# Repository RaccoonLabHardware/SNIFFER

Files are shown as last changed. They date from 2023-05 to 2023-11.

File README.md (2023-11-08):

# SNIFFER v1.4.0 hardware 

| View | Top | Bottom |
| ---- | --- | --- |
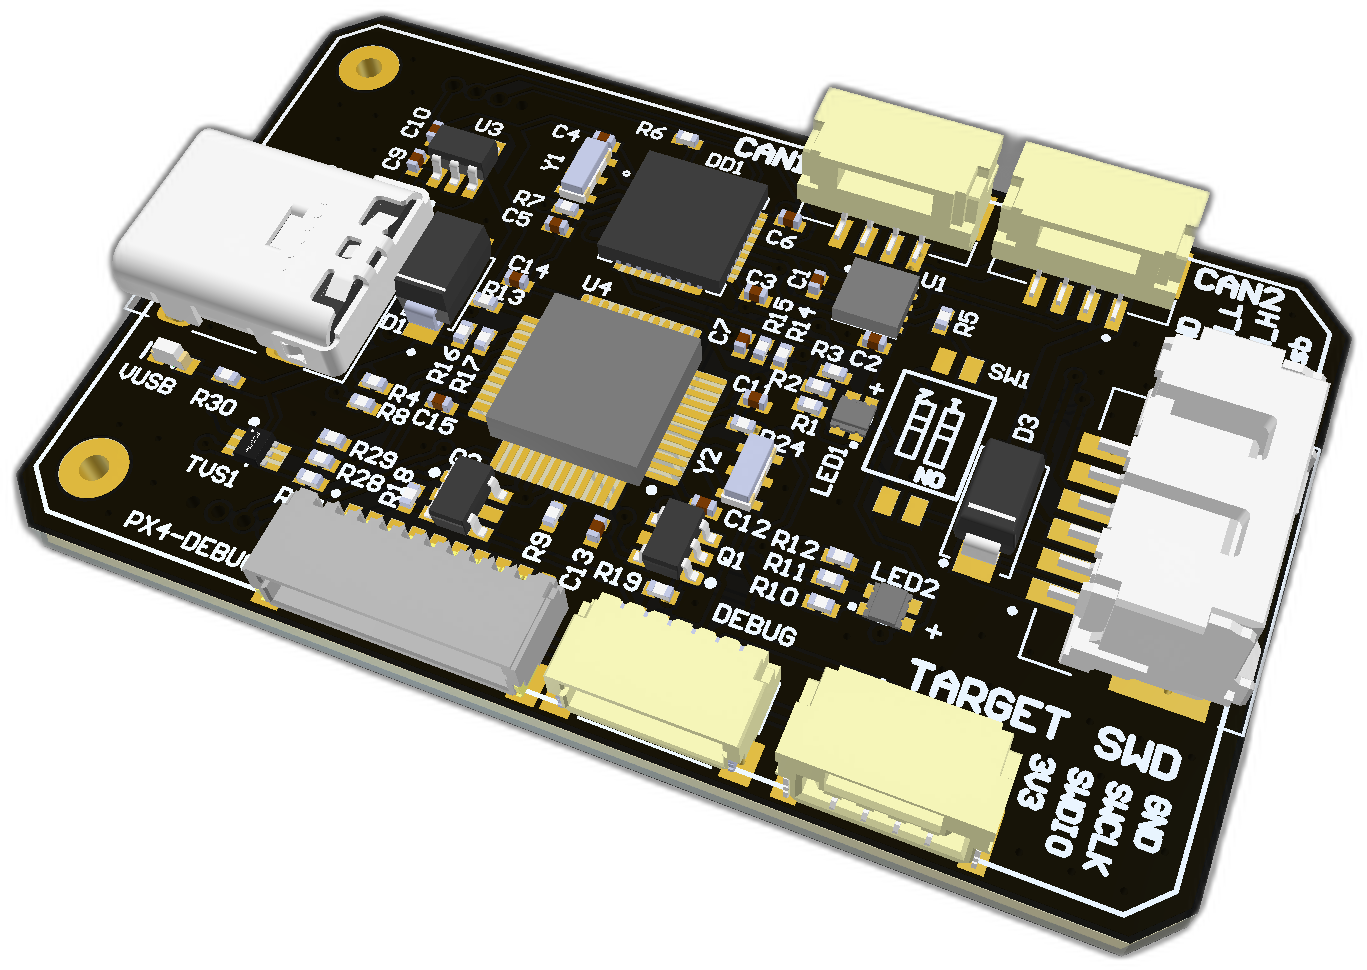
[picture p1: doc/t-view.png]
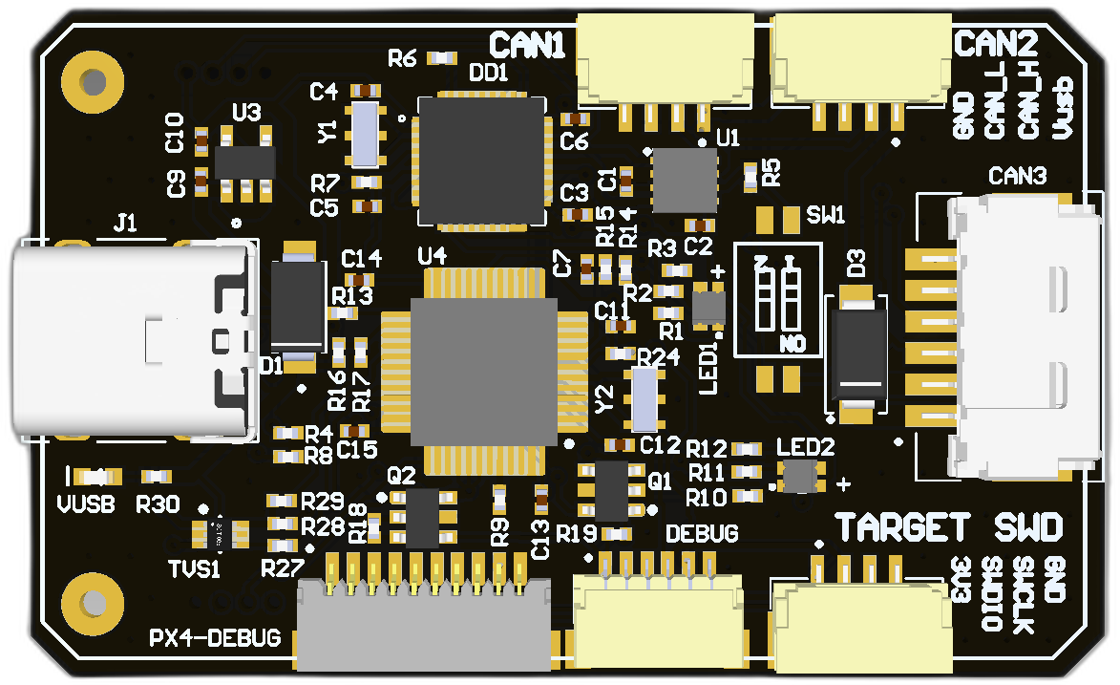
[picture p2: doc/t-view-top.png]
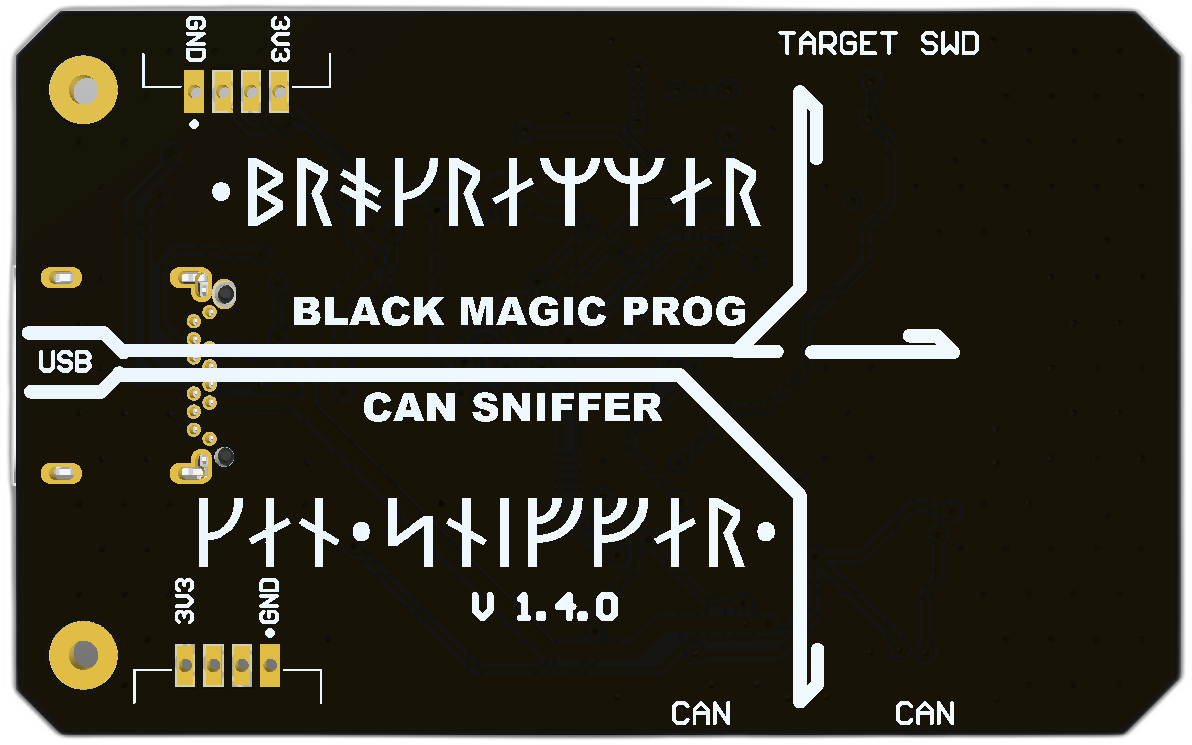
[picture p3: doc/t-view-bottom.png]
|  |  |  |
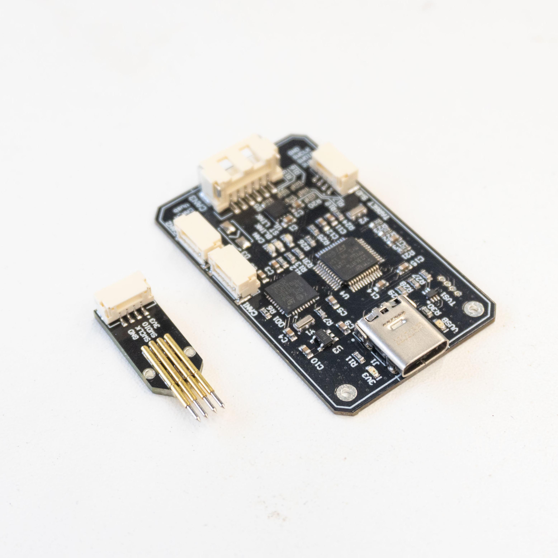
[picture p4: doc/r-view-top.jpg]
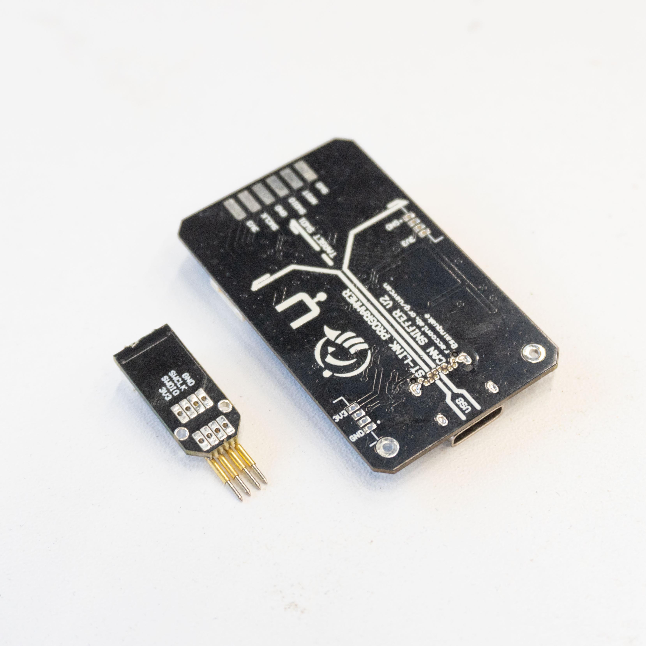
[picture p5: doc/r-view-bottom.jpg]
|  |  |  |

## Features

## Wiring

Schematic features. Schematic can be provided via issue.

**Connectors**

The node has connectors which are described in the table below.

| N | Connector | Description |
| - | - | - |
| 1 | CAN1, CAN2, TARGET SWD |  |
| 2 | CAN3 |  |
| 3 | J1 |  |
| 4 | SWD1, SWD2 |  |

[Here](https://docs.raccoonlab.co/guide/wires/) you can find manufacturer part number of connectors it self and its mates.

## Pin configuration and functions

| Pin N | CAN1 | Pin N | CAN2 | Pin N | TARGETSWD | Pin N | CAN3 | Pin N | J1 | Pin N | SWD1 | Pin N | SWD2 |
| ----- | --- | ----- | --- | ----- | --- | ----- | --- | ----- | --- | ----- | --- | ----- | --- |
| 1 | VBUS | 1 | VBUS | | | 1 | Vin | A1 | GND | 1 | GND | 1 | GND |
| 2 | CAN_H | 2 | CAN_H | | | 2 | Vin | A12 | GND | 2 | SWLK | 2 | SWLK_p |
| 3 | CAN_L | 3 | CAN_L | | | 3 | CAN_H | A4 | VBUS | 3 | SWDIO | 3 | SWDIO_p |
| 4 | GND | 4 | GND | | | 4 | CAN_L | A5 | IP0 | 4 | 3.3 | 4 | 3.3 |
| SH1 | GND | SH1 | GND | | | 5 | GND | A6 | D+ | | | | |
| SH2 | GND | SH2 | GND | 6 | GND | A7 | D- | | | | |
| P1 | GND | A9 | VBUS | | | | |
| P2 | GND | B1 | GND | | | | |
| B12 | GND | | | | |
| B4 | VBUS | | | | |
| B5 | IP1 | | | | |
| B6 | D+ | | | | |
| B7 | D- | | | | |
| B9 | VBUS | | | | |
| SH1 | GND | | | | |
| SH2 | GND | | | | |
| SH3 | GND | | | | |
| SH4 | GND | | | | |
| SH5 | GND | | | | |
| SH6 | GND |

Here you can see all connections of MCU.

| MCU PIN | PIN Numer | NET Name | Description |
| --- |  -- | ---  | - |
| PB13 |  26 | VBUS_SENSE  |  |
| PA8 |  29 | USB_DP_PULLUP  |  |
| PA12 |  33 | USB_DP |  |
| PA11 |  32 | USB_DM |  |
| PA0-WKUP |  7  | TX2/B2 |  |
| PA2 |  9  | TX2/B2 |  |
| PB7 |  43 | TRSWO |  |
| PB3 |  39 | TRACESWO |  |
| PB1 |  16 | T3CH4/ADC9  |  |
| PB0 |  15 | T3CH3/ADC8  |  |
| PA7 |  14 | T3CH2/ADC7  |  |
| PA6 |  13 | T3CH1/ADC6  |  |
| PA14 |  37 | SWLK_p |  |
| PA14/JTCK/SWCLKI/O |  28 | SWLK |  |
| PA13 |  34 | SWDIO_p |  |
| PA13/JTMS/SWDIOI/O |  25 | SWDIO |  |
| NRST |  7  | STM_RST |  |
| PA15/JTDI |  29 | SPI1_SS |  |
| PB3/JTDO |  30 | SPI1_SCK |  |
| PB5 |  32 | SPI1_MOSI |  |
| PB4/JNTRST |  31 | SPI1_MISO |  |
| PB7 |  34 | SDA/A1 |  |
| PB6 |  33 | SCL/A2 |  |
| PA8 |  20 | RXI |  |
| PA9 |  21 | RXI |  |
| PA10 |  31 | RXI |  |
| PA3 |  10 | RX2/B1 |  |
| PA10 |  22 | RX1/C1 |  |
| PA9 |  30 | RX1/C1 |  |
| PB1 |  19 | PWR_BR |  |
| NRST |  4  | NRST |  |
| PD1-OSC_OUT |  6  | NetU4_6 |  |
| PD0-OSC_IN |  5  | NetU4_5 |  |
| PB12 |  25 | NetR13_2 |  |
| BOOT0 |  44 | NetR9_1 |  |
| OSC_OUT/PD1 |  3  | NetDD1_3 |  |
| OSC_IN/PD0 |  2  | NetDD1_2 |  |
| PB0 |  18 | NetC7_2 |  |
| PA5 |  12 | LED_BLUE |  |
| PB11 |  22 | LED2 |  |
| PB10 |  21 | LED1 |  |
| PB2 |  20 | LED0 |  |
| PA4 |  11 | LED |  |
| PA4 |  14 | iTMS_SWDIO  |  |
| PA1 |  11 | iTMS_DIR |  |
| PA6 |  16 | iTDO |  |
| PA3 |  13 | iTDI |  |
| PA5 |  15 | iTCK_SWCLK  |  |
| PA7 |  17 | iRST_SENSE  |  |
| PA2 |  12 | iRST |  |
| VSSA |  5  | GND |  |
| PB2/BOOT1 |  17 | GND |  |
| VSS_2 |  18 | GND |  |
| VSS_3 |  26 | GND |  |
| VSS_1 |  36 | GND |  |
| VSSA |  8  | GND |  |
| VSS_1 |  23 | GND |  |
| VSS_2 |  35 | GND |  |
| VSS_3 |  47 | GND |  |
| PA12 |  24 | CAN_TXD |  |
| PA11 |  23 | CAN_RXD |  |
| BOOT0 |  35 | BOOT0 |  |
| PA1 |  8  | ADC_5V |  |
| VDD_1 |  1  | 3.3 |  |
| VDDA |  6  | 3.3 |  |
| VDD_2 |  19 | 3.3 |  |
| VDD_3 |  27 | 3.3 |  |
| VBAT |  1  | 3.3 |  |
| VDDA |  9  | 3.3 |  |
| VDD_1 |  24 | 3.3 |  |
| VDD_2 |  36 | 3.3 |  |
| PB4 |  40 | 3.3 |  |
| PB5 |  41 | 3.3 |  |
| PB6 |  42 | 3.3 |  |
| VDD_3 |  48 | 3.3 |  |

## Specifications

**Mechanical**

Scheme is shown on the picture below. CAN model can be provided via email request or issue on github or downloaded on GrabCAD (opens new window).

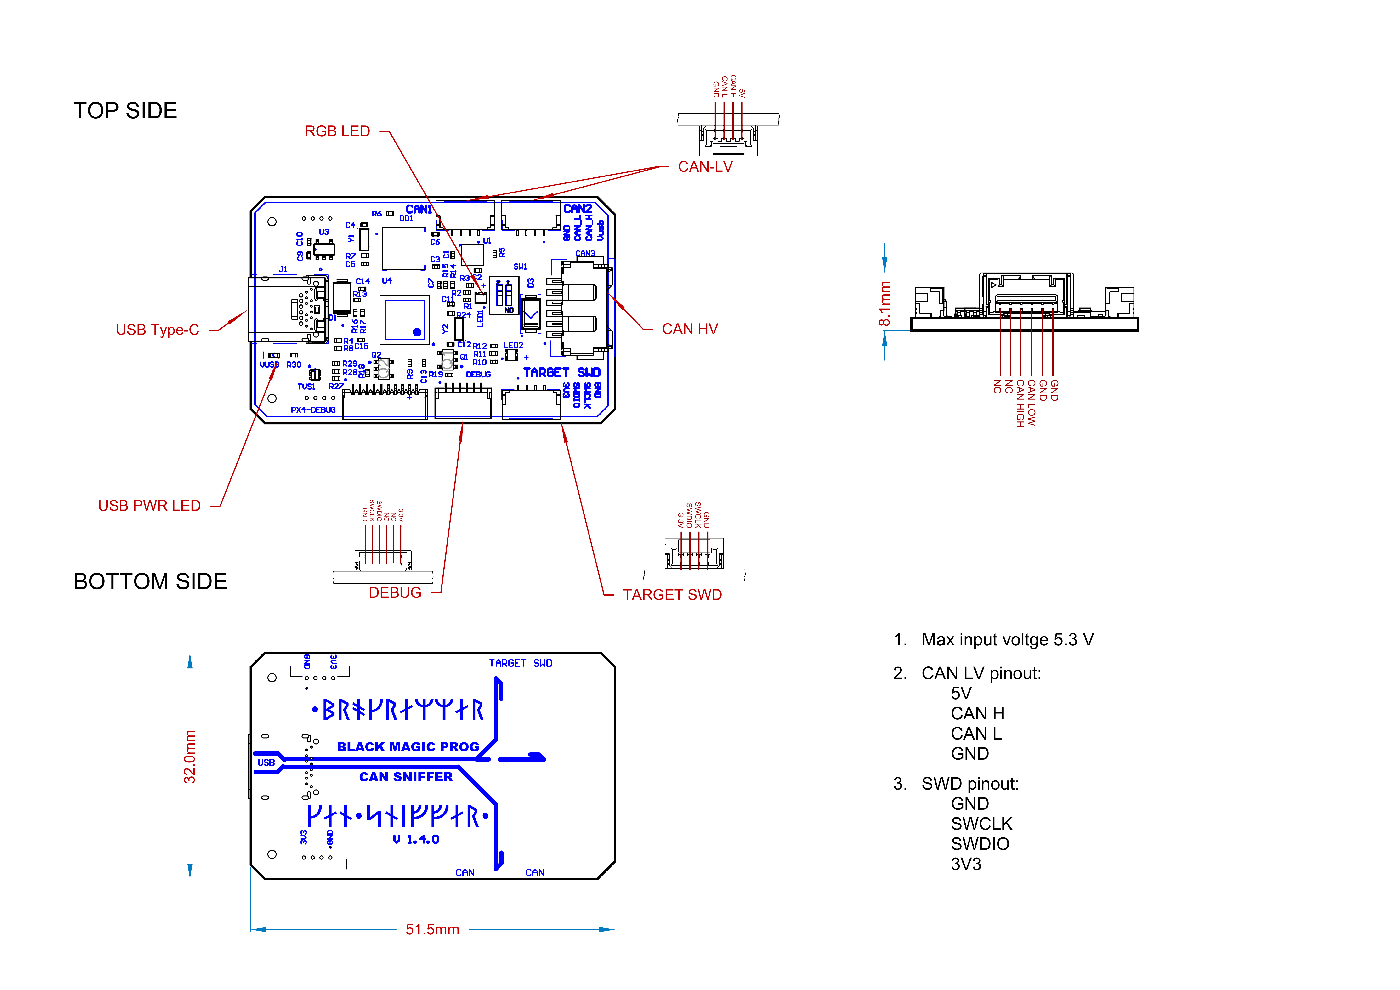
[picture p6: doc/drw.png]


| | Width, mm | Length, mm | Height, mm |
| ----- | --- | --- | --- |
|Outline| 51.9 | 32.0 | 8.1 |
|PCB | 51.5 | 32.0 | 1.6 |

Total weight of device less than 50 g.

### Housing

Information about case presented here.

### Absolute Maximum Ratings

### Recommended operating conditions

### ESD ratings

### MTFF

## Integration

**Recommended mechanical mounting**

**Connection example diagram**

### Power Supply Recommendations

Device is designed to operate from an input voltage supply range between 4.5 V and 5.5 V over CAN2 or CAN3 connector, or 5.5 - 30 V from CAN1. This input supply must be able to withstand the maximum input current and maintain a stable voltage. The resistance of the input supply rail should be low enough that an input current transient does not cause a high enough drop that can cause a false UVLO fault triggering and system reset. The amount of bulk capacitance is not critical, but a 47-uF or 100-uF electrolytic capacitor is a typical choice.

## Revision history

|View |Version| Date| Description|
|- |- |- |- |

## Order details

### PCB Specification Selection

- Board type : Panel by PCBWay
- Break-away rail: Yes
- Instructions:
~~~
Final size is larger ( 51.9 x 32.0 mm ) than board it self ( 51.5 x 32.0 mm), 
take a look at the picure in attachements. 
Panel should be designed to be able to install PWM1, PWM2 while assembly.
~~~
- Route Process: Panel as PCBWay prefer
- X-out Allowance in Panel:  Accept

- Size (single): 51.5 x 32.0 mm
- Quantity (single): 200
- Layers: 2 -   ['Top Layer', 'Bottom Layer'] check [PCBway layer stack](https://www.pcbway.com/multi-layer-laminated-structure.html)

- Material: FR-4
- FR4-TG: TG 150-160
- Thickness: 1.6
- Min Track/Spacing: 7/7mil (0.17 mm)
- Min Hole Size: 0.3 mm
- Solder Mask: Black
- Silkscreen: White
- Edge connector: No
- Surface Finish: HASL with lead
- Yes - Tick means you accept we might change "HASL" to "ENIG" at our discretion without extra charge.
- Via Process: Tenting vias
- Finished Copper: 1 oz Cu
- Other Special request:
~~~
Final size is larger ( 51.9 x 32.0 mm ) than board it self ( 51.5 x 32.0 mm )
~~~

### Assembly Service

- Turnkey
- Board type : Panelized PCBs
-  Assembly Side(s): Both sides
- Quantity: 200
- Contains Sensitive components/parts - No; 
- Do you accept alternatives/substitutes made in China? - Yes

- Number of Unique Parts: 0
- Number of SMD Parts: 0
- Number of BGA/QFP Parts: 0
- Number of Through-Hole Parts: 0

### Additional Options

- Firmware loading: Yes
- Detailed information of assembly:
~~~
Firmware is in attachements.
Take a look at the picure in attachements should be installed from the side.
~~~

## Device and Documentation Support

- [User manual]()
- [Hardware docs](doc/doc.pdf)

## Device Support

- [Firmware sources]()
- [Firmware binary]()

## TERMS OF USAGE / LICENCE

The material provided in this Github repository is subject to the following conditions. 

Firmware files: All firmwares are free (but not open source). Besides unlimited private use you are also granted the permission to use them for commercial purposes under the condition that (1) you dont modify the firmware, e.g. remove or change copyright statements, (2) provide it for free, i.e. dont charge any explicit or implicit fees to your customers, and (3) correctly and clearly cite the origin of the firmware and the project web page in any product documentation or web page. 

Hardware files: All hardware, for which material is provided, is open source hardware, under the terms of the TAPR Open Hardware License as published by the Free Hardware Foundation, see http://www.tapr.org/ohl.html. The TAPR license explicitly permits essentially unlimited commercial use, with only few conditions such as that copyright logos are not removed.

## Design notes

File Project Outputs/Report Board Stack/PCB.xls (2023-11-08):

Board Stack Report
Stack Up |  | Layer Stack
Layer | Board Layer Stack | Name | Material | Thickness | Constant
1 |  | Top Paste
2 |  | Top Overlay
3 |  | Top Solder | Solder Resist | 0,010mm | 3,5
4 |  | Top Layer | Copper | 0,050mm
5 |  | Dielectric 1 | FR-4 | 1,600mm | 4,8
6 |  | Bottom Layer | Copper | 0,050mm
7 |  | Bottom Solder | Solder Resist | 0,010mm | 3,5
8 |  | Bottom Overlay
9 |  | Bottom Paste
 | Height : 1,720mm

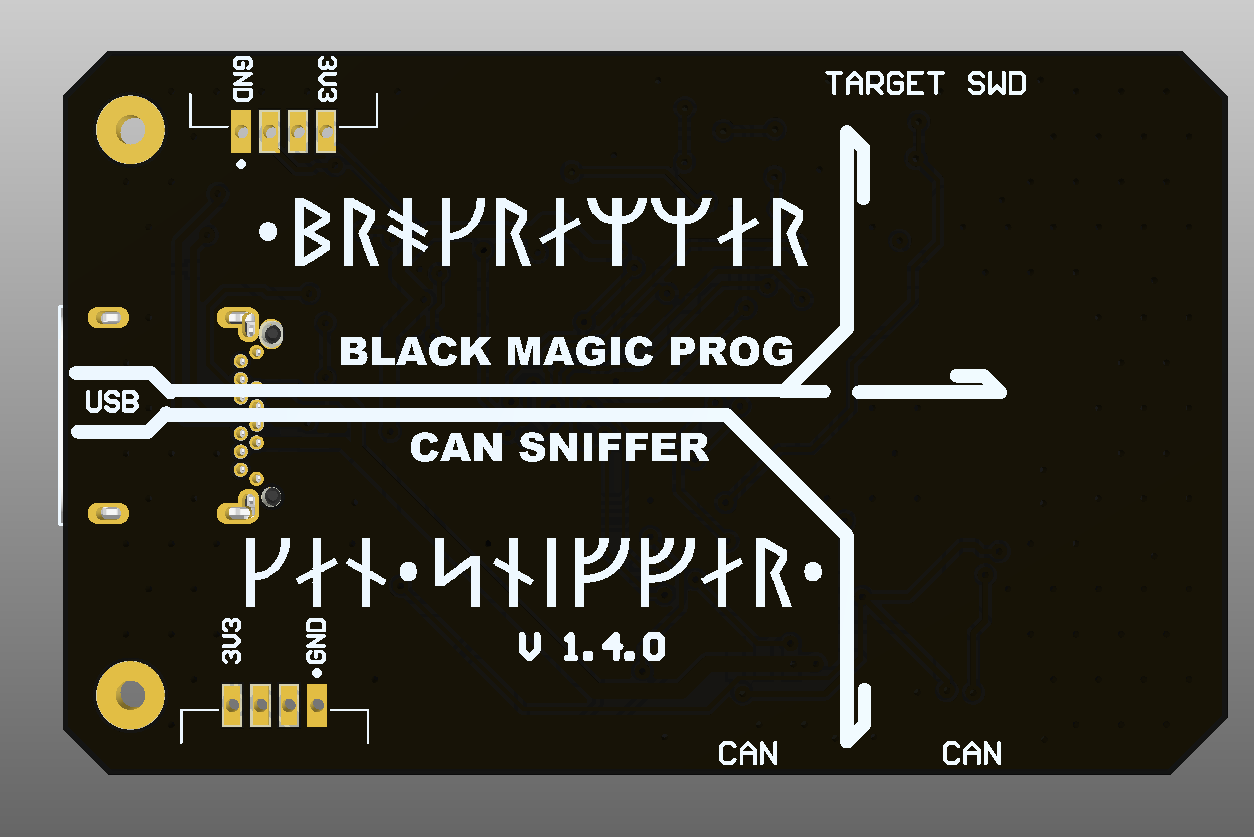
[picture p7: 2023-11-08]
doc/view-bottom.png

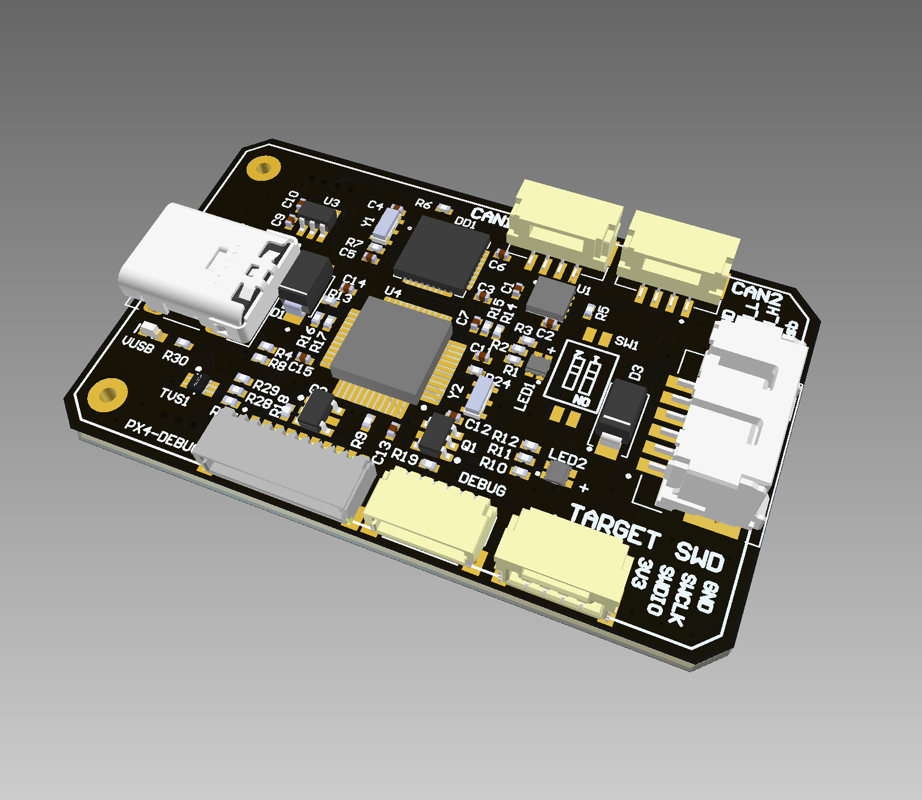
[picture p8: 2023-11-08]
doc/view.png

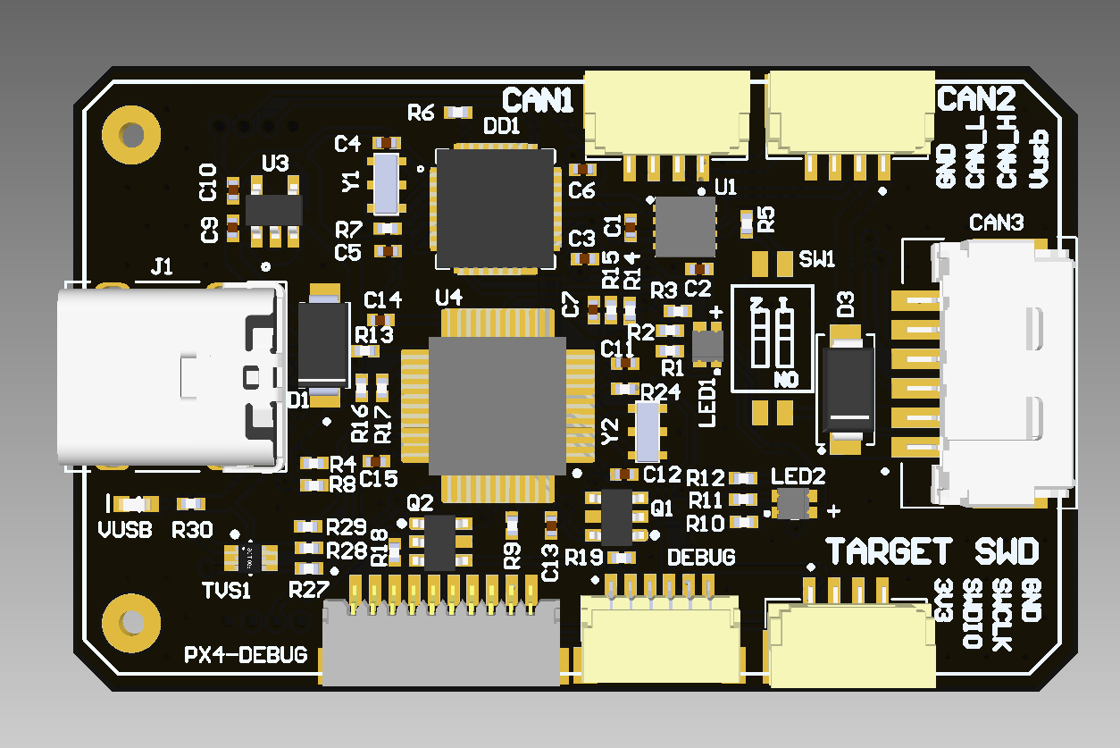
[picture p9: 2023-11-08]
doc/view-top.png

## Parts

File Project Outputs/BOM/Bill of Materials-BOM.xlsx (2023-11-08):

Designator | Quantity | MF | MP | Description | Value | Package | Type | Instructions | HelpURL | System
C1, C2, C3, C4, C5, C6, C7, C9, C10, C11, C12, C13, C14, C15 | 14 | Murata | GCM155R71H104KE02D | GCM155R71H104KE02D, Чип 0402 X7R 0.1uF +10% 50V,Конденсатор | 0.1u | 0402 | SMD
CAN1, CAN2, TARGET SWD | 3 | JST Sales | SM04B-GHS-TB(LF)(SN) | Connector Header Surface Mount, Right Angle 4 position 0.049 _1.25mm_ |  | None | SMD |  | http://www.farnell.com/datasheets/2082975.pdf | Connector
CAN3 | 1 | Molex | 502585-0670 | 1.50mm Pitch, CLIK-Mate PCB Receptacle, Single Row, Surface Mount, Right-Angle, Tin Plating, Positive Lock, 6 Circuits, Natural |  | None | SMD |  |  | Connector
D1 | 1 | Taiwan Semiconductor | SMAJ5.0 | 400W, 6.9V, 10%, Unidirectional, TVS |  | DO-214AC-2 Taiwan Semiconductor | SMD
D3 | 1 |  | SS16 | Diode Schottky 60V 1A Surface Mount SMA |  | SMA-2 | SMD | DNP
DD1 | 1 | STM | STM32F103T8U6 | STM32F103T8U6, Микроконтроллер 32BIT ARM 64K FLASH [VFQFPN-36] |  | VFQFPN-36 | SMD |  | http://www.st.com/stonline/products/literature/ds/13587.pdf
DEBUG | 1 | JST Sales | SM06B-SRSS-TB_LF__SN_ | Connector Header Surface Mount, Right Angle 6 position 0.039 _1.00mm_ |  | None | SMD |  | https://www.farnell.com/datasheets/2082363.pdf
J1 | 1 | CUI Devices | UJ31-CH-31N-SMT-TR | Type C, USB 3.1 Gen 2, 5 A, Right Angle, Surface Mount _SMT_, USB Receptacle |  | None | SMT |  | https://www.chipdip.ru/product1/8002862225 | Connector
LED1, LED2 | 2 |  | LTST-C19HE1WT | Blue/Green/Red |  |  | SMD |  | https://static.chipdip.ru/lib/039/DOC013039662.pdf
PX4-DEBUG | 1 | JST Sales | SM10B-SRSS-TB |  |  | SM10B-SRSS-TB |  |  | https://www.farnell.com/datasheets/2082363.pdf
Q1 | 1 | Infineon | IRF5852 | Mosfet Array 2 N-Channel _Dual_ 20V 2.7A 960mW Surface Mount 6-TSOP |  | TSOP-6 International Rectifier |  |  | https://static.chipdip.ru/lib/300/DOC000300076.pdf
Q2 | 1 | Infineon | IRF5850 | Mosfet Array 2 P-Channel (Dual) 20V 2.2A 960mW Surface Mount 6-TSOP |  | TSOP-6 International Rectifier
R1, R2, R3, R10, R11, R12 | 6 | Yageo or NXP | RC0402FR-07330RL | 0.062Вт 0402 330 Ом, 1%, Чип резистор (SMD) | 330 | RC0402 | SMD |  | https://www.chipdip.ru/product0/9000189640
R4, R8 | 2 | Yageo or NXP | RC0402FR-075K1L | 0.062Вт 0402 5.1 кОм, 1%, Чип резистор (SMD) | 5.1k | RC0402 | SMD |  | https://www.chipdip.ru/product0/9000189640
R5 | 1 | Yageo or NXP | RC0402FR-07120RL | 0.062Вт 0402 120 Ом, 1%, Чип резистор (SMD) | 120 | RC0402 | SMD |  | https://www.chipdip.ru/product0/9000189640
R6, R7, R9, R13, R15, R17, R18, R19, R24 | 9 | Yageo or NXP | RC0402FR-0710KL | 0.062Вт 0402 10 кОм, 1%, Чип резистор (SMD) | 10k | RC0402 | SMD |  | https://www.chipdip.ru/product0/9000189640
R14, R16 | 2 | Yageo or NXP | RC0402FR-074K7L | 0.062Вт 0402 4.7 кОм, 1%, Чип резистор (SMD) | 4.7k | RC0402 | SMD |  | https://www.chipdip.ru/product0/9000189640
R27, R28 | 2 | Yageo or NXP | RC0402FR-0722RL | 0.062Вт 0402 22 Ом, 1%, Чип резистор (SMD) | 22 | RC0402 | SMD |  | https://www.chipdip.ru/product0/9000189640
R29 | 1 | Yageo or NXP | RC0402FR-071K6L | 0.062Вт 0402 1.6 кОм, 1%, Чип резистор (SMD) | 1.6k | RC0402 | SMD |  | https://www.chipdip.ru/product0/9000189640
R30 | 1 | Yageo or NXP | RC0402FR-071KL | 0.062Вт 0402 1 кОм, 1%, Чип резистор (SMD) | 1k | RC0402 | SMD |  | https://www.chipdip.ru/product0/9000189640
SW1 | 1 | KINGTEK INDUSTRIAL | DSHP02TSGER | DSHP Series 1.27mm Pitch DIP Switch 4 POS |  | None |  |  | https://item.szlcsc.com/3856577.html
SWD1, SWD2 | 2 | JST Sales | SM04B-GHS-TB(LF)(SN) | Conn Shrouded Header HDR 4 POS 1.25mm Solder ST SMD Reel |  | None | SMD | DNP |  | Connector
TVS1 | 1 | STM | USBLC6-2P6 | 17V Clamp 5A (8/20µs) Ipp Tvs Diode Surface Mount SOT-666 |  | SOT-666 | SMD |  | https://static.chipdip.ru/lib/093/DOC001093117.pdf
U1 | 1 | NXP USA | TJA1042TK/3 | 1/1 Transceiver Half CANbus 8-SO |  | VDFN-8 NXP USA | SMD |  | https://static.chipdip.ru/lib/583/DOC001583059.pdf
U3 | 1 | MaxLinear, Inc. | SPX3819M5-L-3-3/TR | Low Dropout Voltage Regulator, Adjustable 0.5A, В±1%, 2.5 to 16 Vin, 5-Pin SOT-23 | 3V3 | SOT-23-5 Exar | SMD |  | http://www.farnell.com/datasheets/2614478.pdf
U4 | 1 | STM | STM32F103CBT6 | ARM® Cortex®-M3 STM32F1 Microcontroller IC 32-Bit 72MHz 128KB (128K x 8) FLASH |  | LQFP-48 | SMD | STM32F103CBT6 - should be B letter not 8 | https://static.chipdip.ru/lib/235/DOC000235733.pdf
VUSB | 1 |  | LTST-C194KFKT | Orange 605nm LED Indication - Discrete 2.2V 0603 (1608 Metric) | ORANGE | 0603 Lite-On | SMD
Y1, Y2 | 2 | Murata | CSTCE8M00G55-R0 | Ceramic Resonator 8MHz ??0.5% _Tol_ ??0.2% _Stability_ 33pF 40Ohm 3-Pin CSMD T/R |  | SMD-3 Murata | SMD |  | https://www.murata.com/en-eu/api/pdfdownloadapi?cate=&partno=CSTCE8M00G55-R0

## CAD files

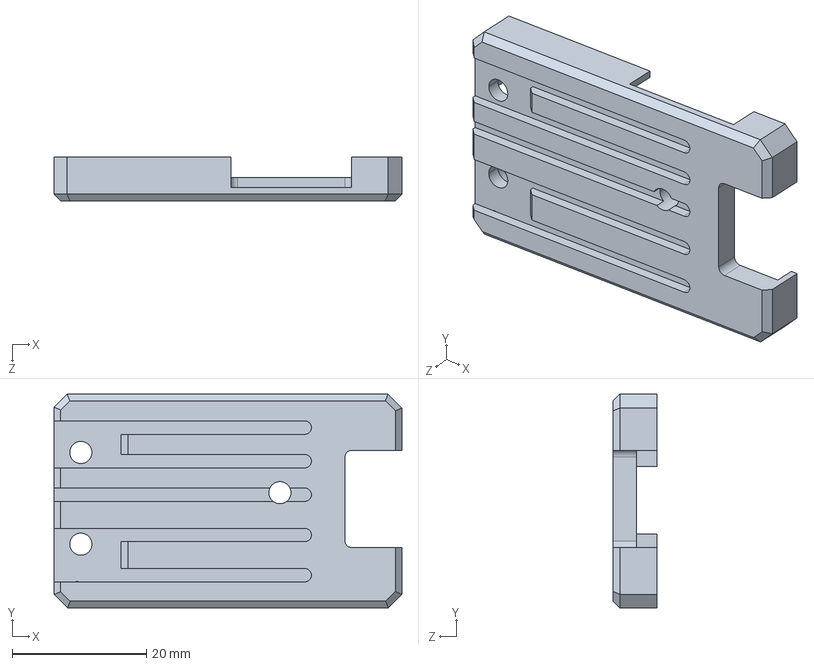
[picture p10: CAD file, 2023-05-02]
housing/housing.STEP
51.9 x 31.9 x 6.50 mm

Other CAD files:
housing/housing.SLDASM
housing/housing.SLDDRW
housing/housing.SLDPRT

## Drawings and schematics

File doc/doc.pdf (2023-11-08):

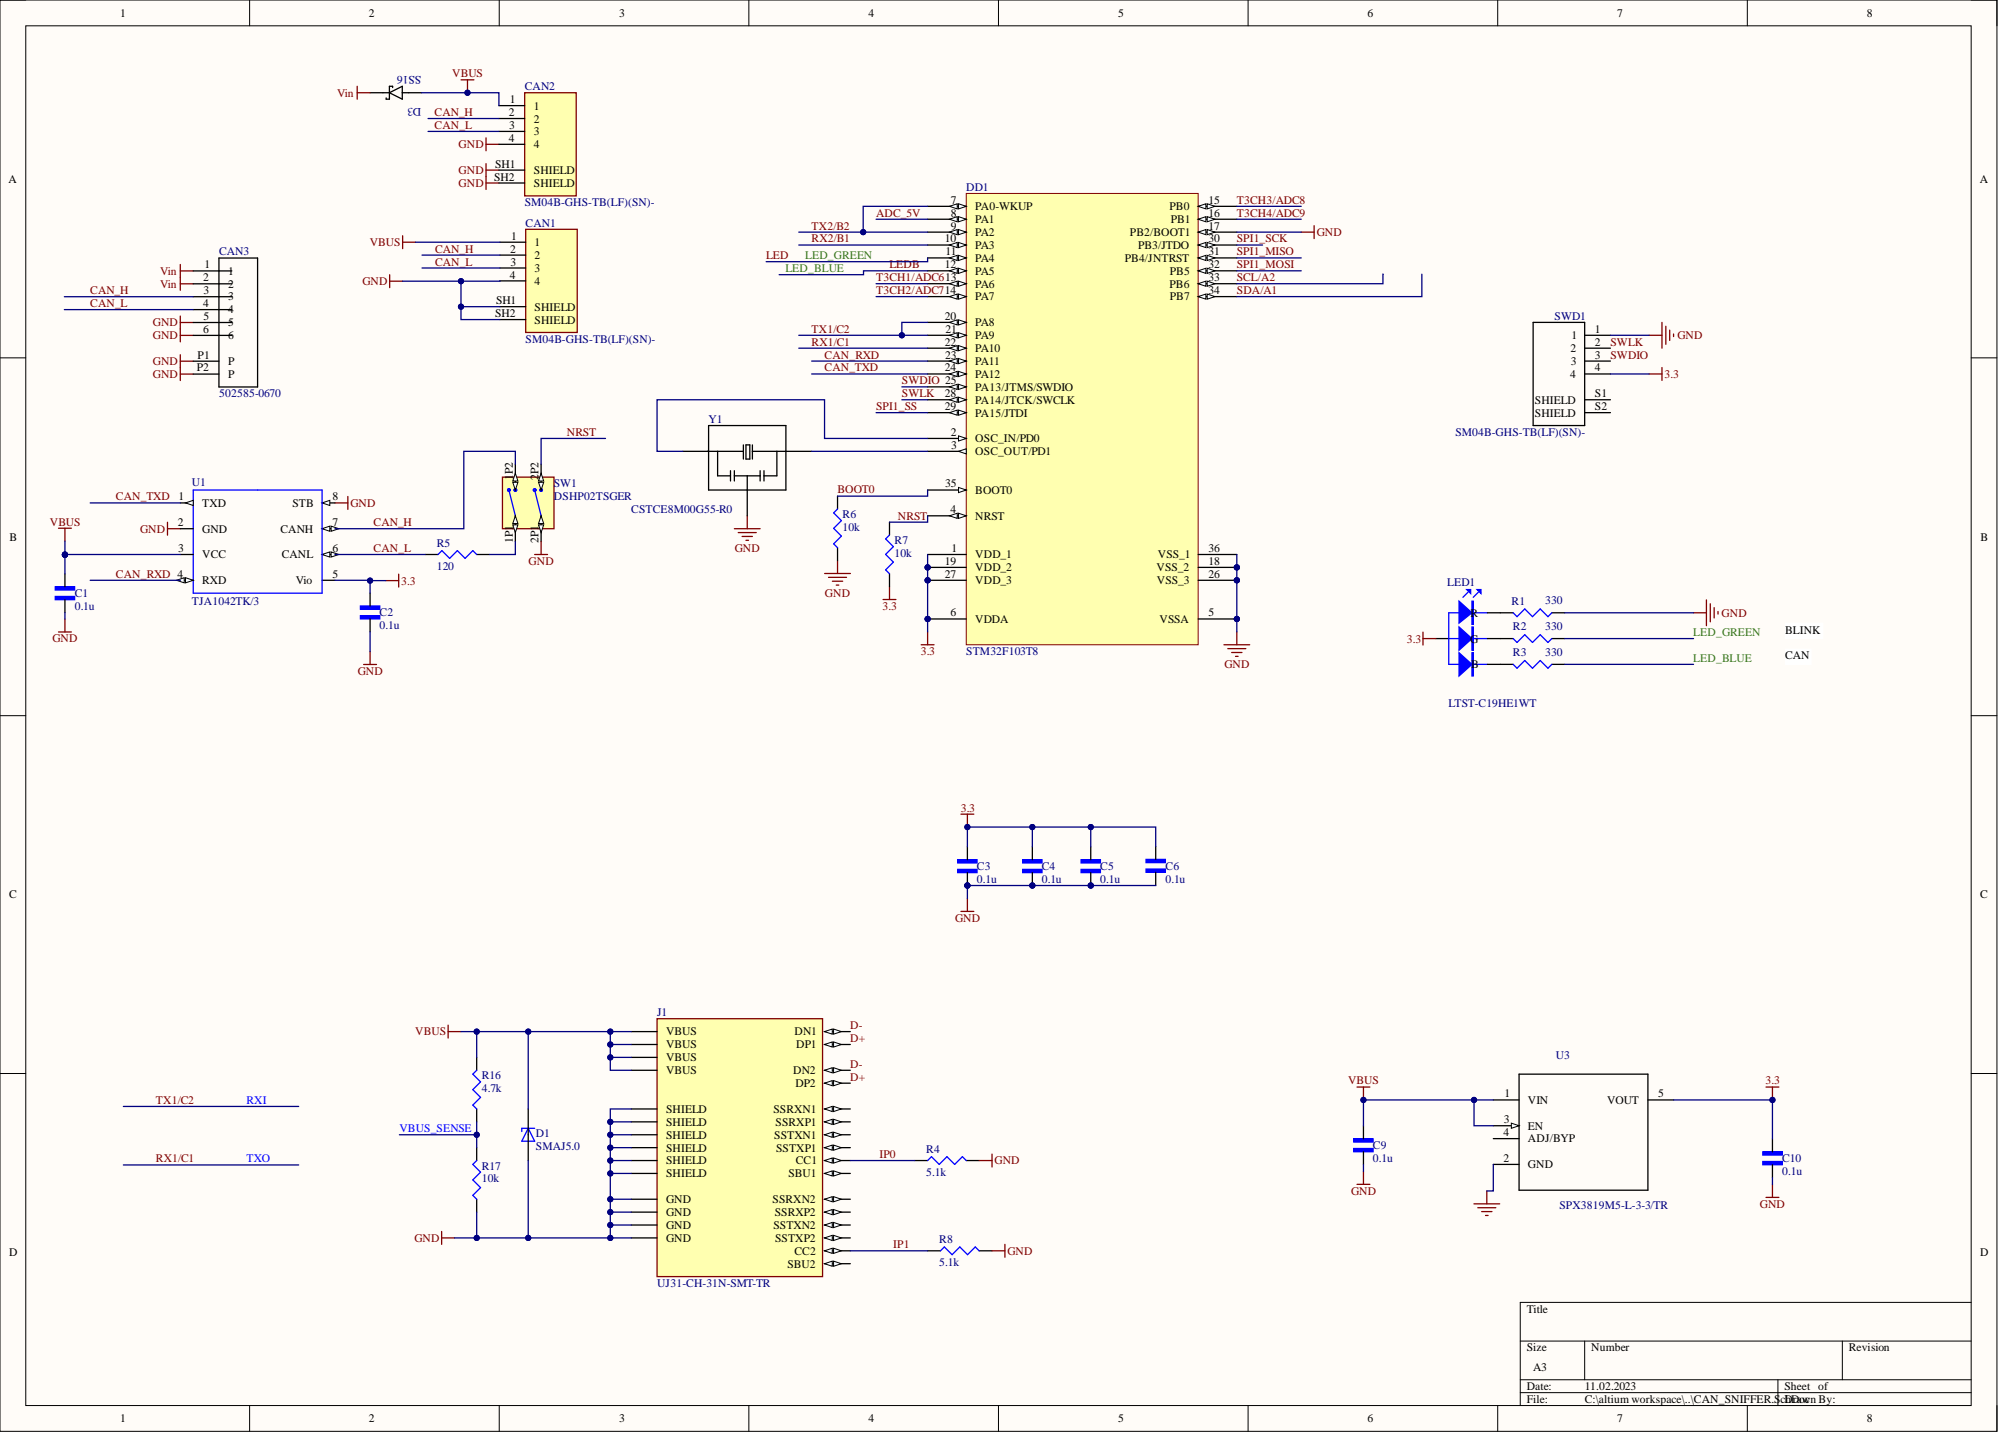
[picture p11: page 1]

SM04B-GHS-TB(LF)(SN)-

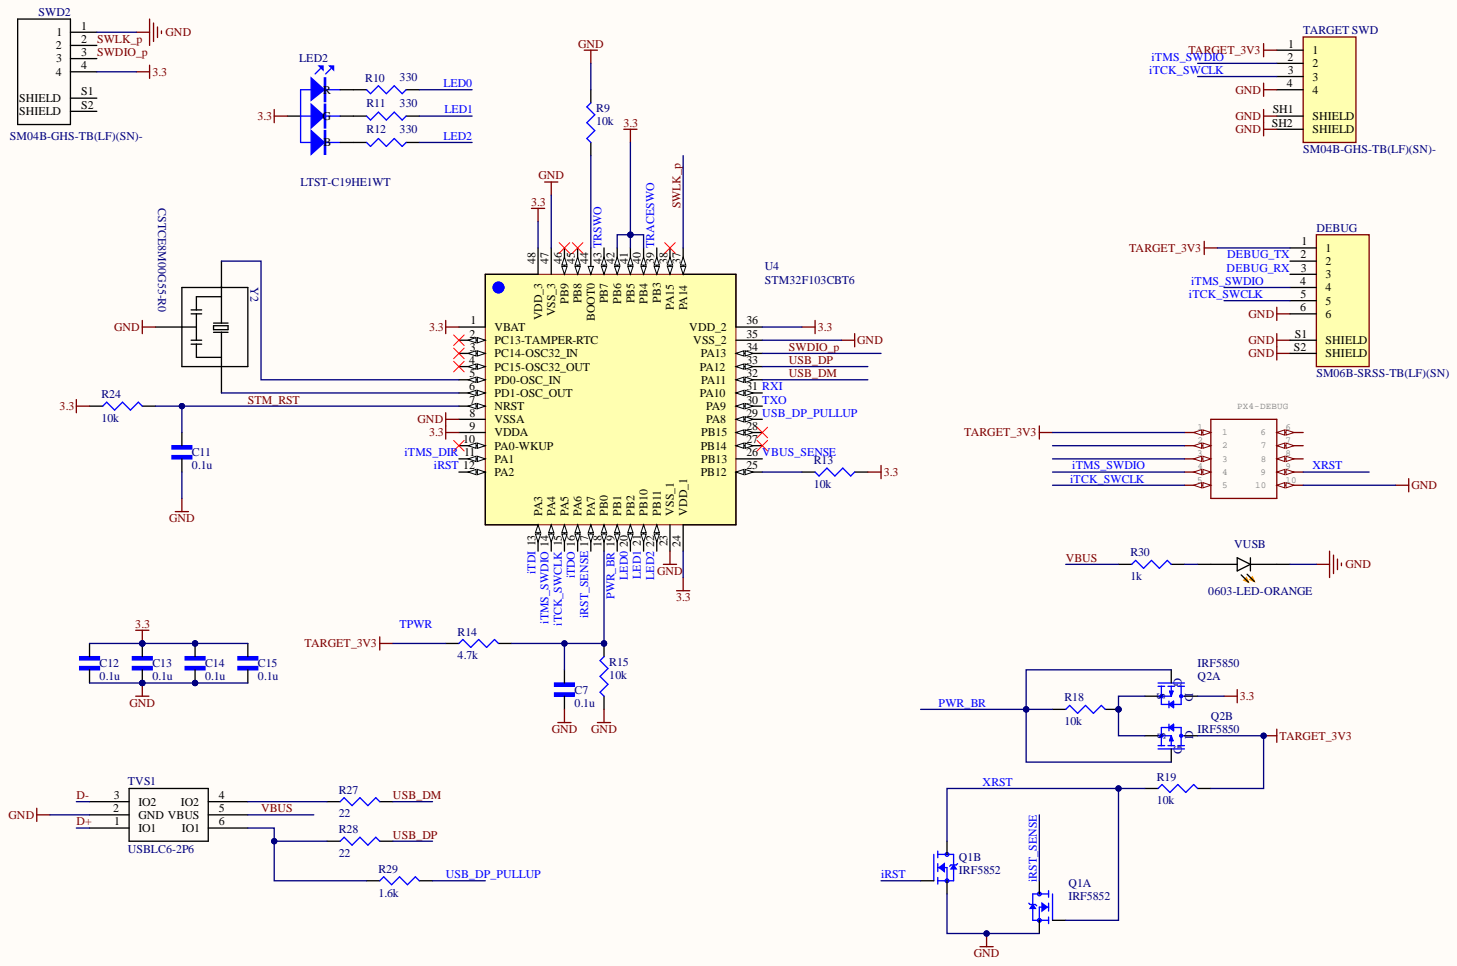
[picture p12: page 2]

SM04B-GHS-TB(LF)(SN)-

SM06B-SRSS-TB(LF)(SN)

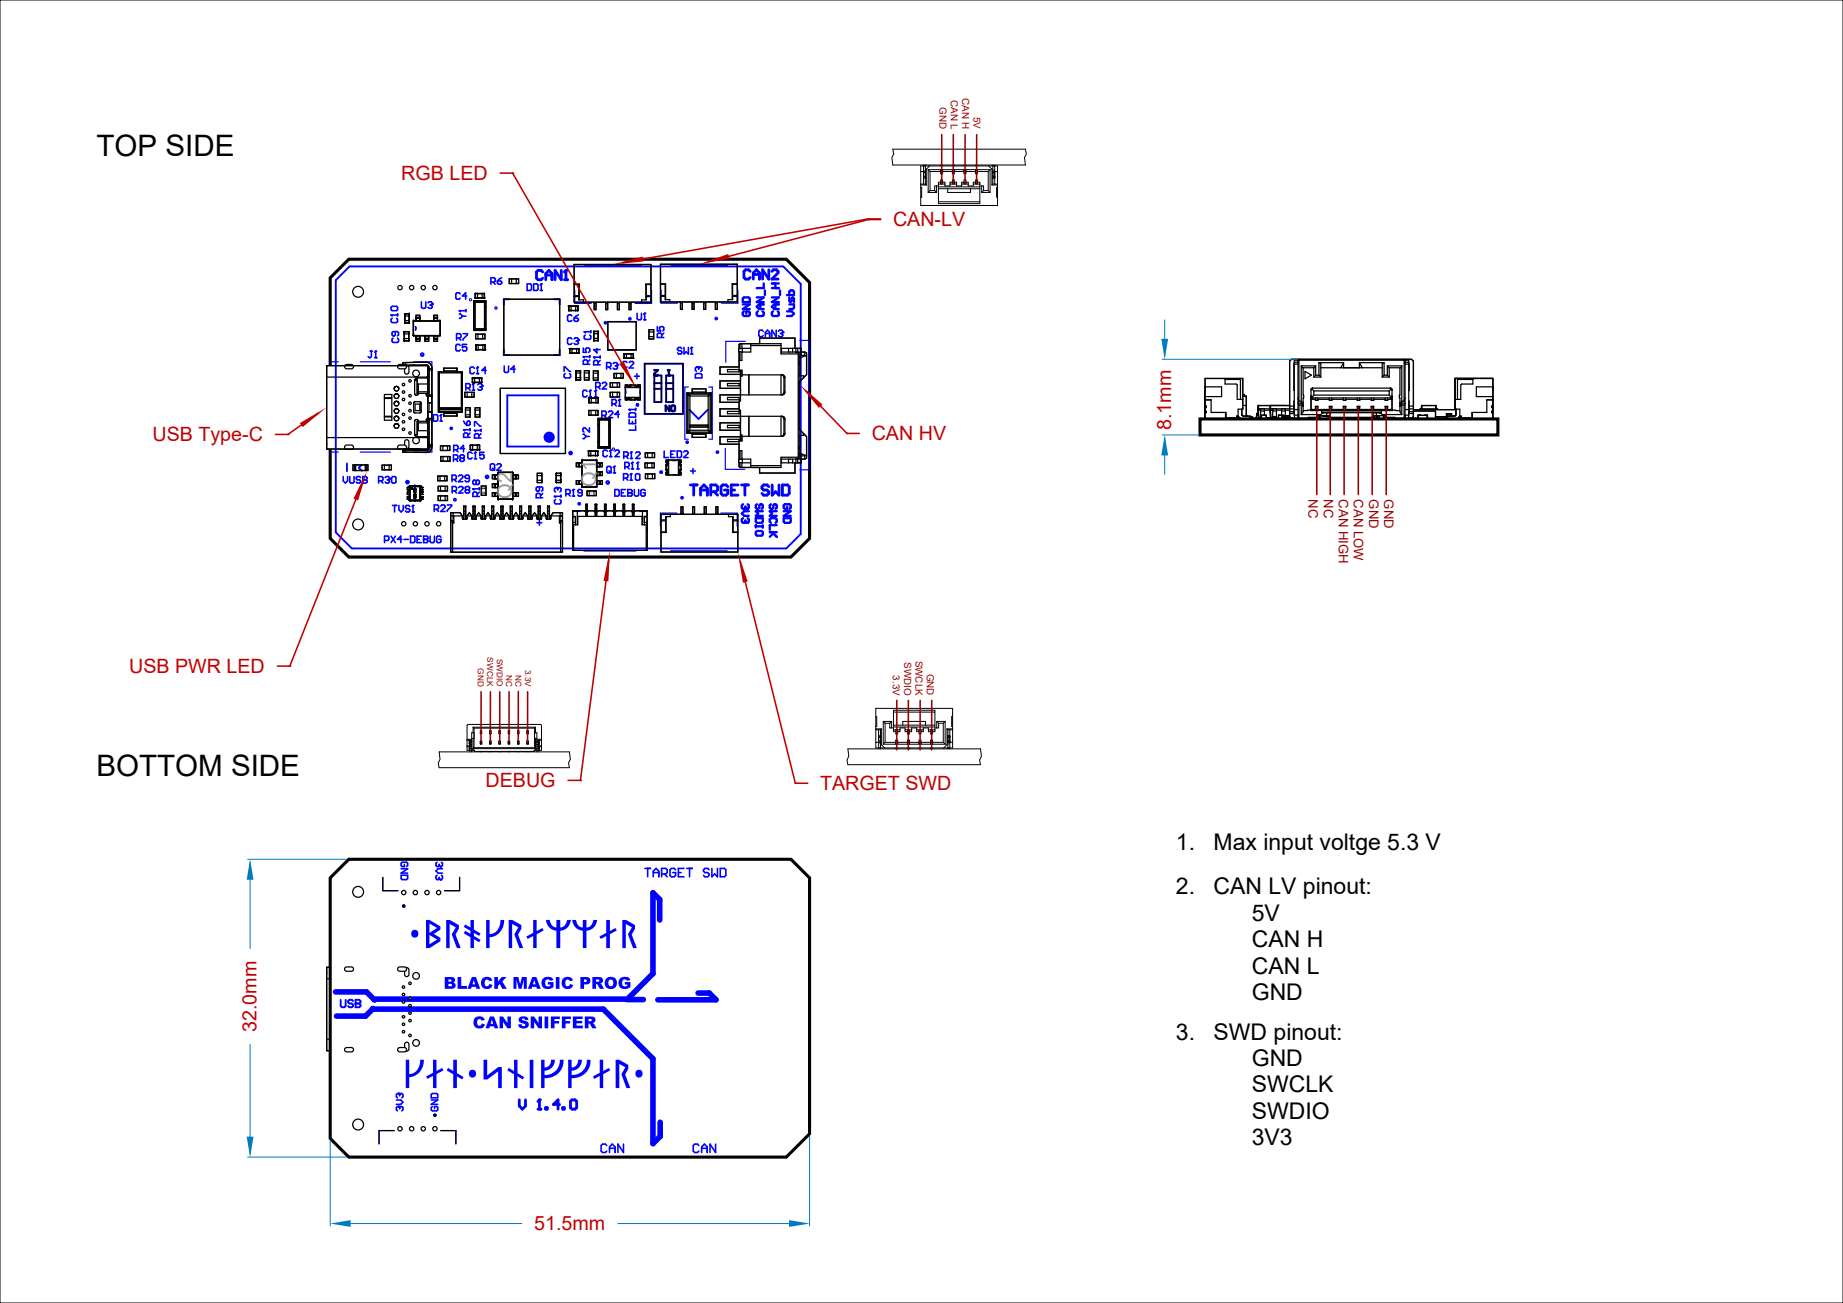
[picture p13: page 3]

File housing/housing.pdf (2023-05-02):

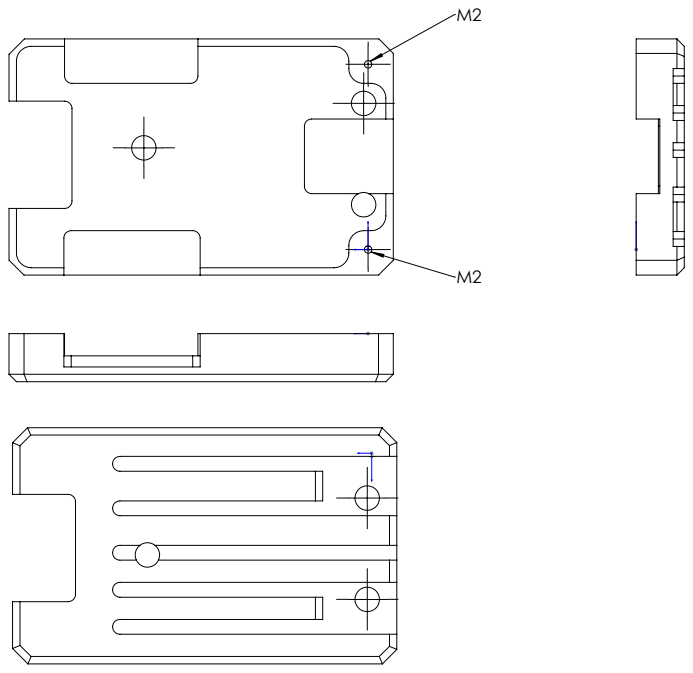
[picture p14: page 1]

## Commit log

2020-11-02 release to order 5
    [CAN_SNIFFER.PcbDoc, CAN_SNIFFER.PrjPcb, CAN_SNIFFER.SCHLIB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]
2021-08-24 release version 2. job and BOM files set up
    [Bill of Materials-BOM.xlsx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]
2021-11-12 cad files added
    [CAN_SNIFFER.SLDDRW]
2022-04-21 update for new order. second CAN added
    [Bill of Materials-BOM.xlsx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]
2022-10-07 update text on board
    [Bill of Materials-BOM.xlsx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]
2022-10-11 release silkscreen corrections, diode added
    [Bill of Materials-BOM.xlsx, CAN_SNIFFER.SchDoc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]
2022-11-10 DEBUG port added
    [CAN_SNIFFER.SchDoc, PCB.PcbDoc, SNIFFER.PrjPcb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]
2022-11-14 g0 update
    [CAN_SNIFFER.SchDoc, SNIFFER.PrjPcb, STLINKv2DIY.SchDoc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]
2022-11-14 remove docs
    [Bill of Materials-BOM.xlsx, CAN_SNIFFER.SCHLIB, CAN_SNIFFER.SLDDRW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]
2023-05-02 update to v1.3
    [CAN_SNIFFER.SchDoc, SNIFFER.PrjPcb, STLINKv2DIY.SchDoc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]
2023-05-02 update with new tests
    [housing.STEP]
2023-05-02 outputs for tests
    [Bill of Materials-BOM.xlsx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]
2023-05-02 type-c should work now
    [CAN_SNIFFER.SchDoc, SNIFFER.PrjPcb]
2023-05-25 release version
    [Bill of Materials-BOM.xlsx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]
2023-11-08 Pr black magic (#3)
    * routed
    * outputs and precommit
    * Delete output.xlsx
    * updated
    * update pics
    * update with 2 mosfets
    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
    [Bill of Materials-BOM.xlsx, CAN_SNIFFER.SchDoc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]
